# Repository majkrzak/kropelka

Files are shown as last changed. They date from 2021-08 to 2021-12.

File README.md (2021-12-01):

kropelka
========

Fluid level ISM band radio sensor.

Introduction
------------

Aim of the project was to utilise the cc1101 board I recently acquired. Because of the last events in my neighbourhood, I came up with idea of creating the sensor detecting water level above the threshold.

Electronic Parts
-----

### ATtiny13A
Atmel picoPower 8-Bit AVR microcontroller.

### E07 M1101-SMA
EBYTE CC1191 Wireless Module.

### DFR0579
DFRobot Solar Power Manager Micro.

### Solar Panel
DFRobot 2V 160mA Solar Panel.

### Lipo battery
Akyga Li-Pol cell 190mAh 1S 3,7V

### CMW55
Magnetic fluid level sensor.

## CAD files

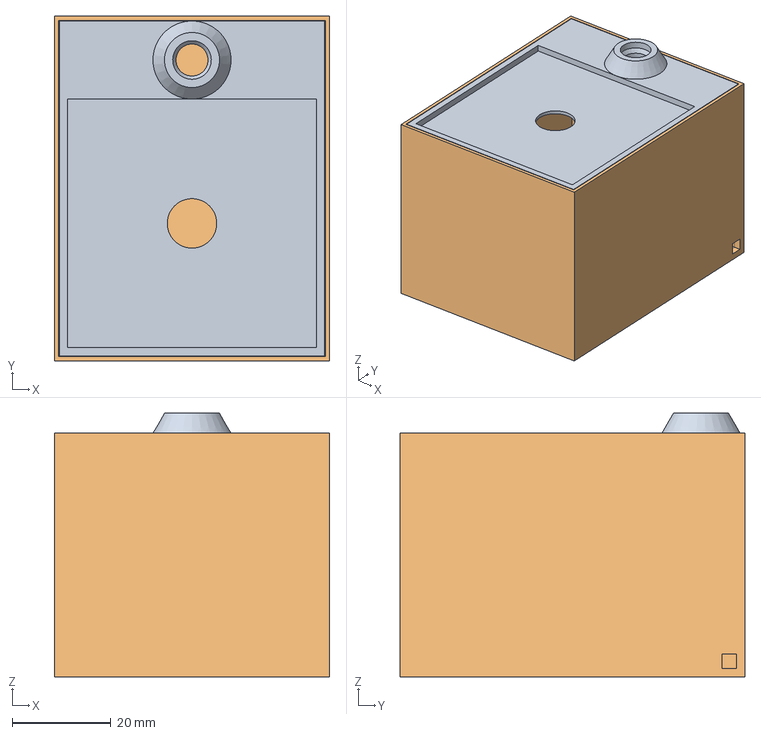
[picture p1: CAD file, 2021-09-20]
case/case.FCStd
55.7 x 69.8 x 53.3 mm
Lead

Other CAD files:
case/case.obj

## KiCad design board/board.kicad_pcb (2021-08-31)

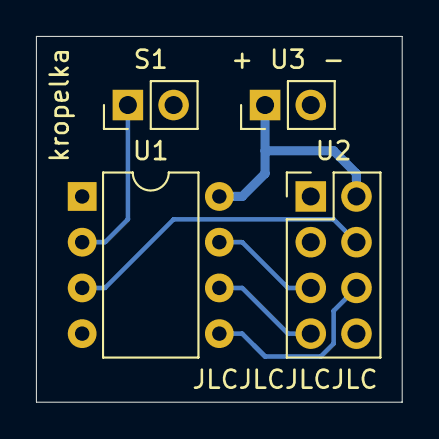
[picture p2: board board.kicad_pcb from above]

Board: 2 copper layers, 20.3 x 20.3 mm, 4 parts (0 on the bottom side), 7 nets.

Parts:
S1: Float_Switch; PinHeader_1x02_P2.54mm_Vertical
U1: ATtiny13A-PU; DIP-8_W7.62mm
U2: E07-M1101D
U3: DFR0579; PinHeader_1x02_P2.54mm_Vertical

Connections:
GND: S1.2, U1.4, U2.1, U3.2
unnamed: S1.1, U1.2
unnamed: U1.3, U2.4
unnamed: U1.5, U2.6
unnamed: U1.6, U2.7
unnamed: U1.7, U2.5
VCC: U1.8, U2.2, U3.1

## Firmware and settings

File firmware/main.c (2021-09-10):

#include "cc1101.h"
#include "mcu.h"
#include "radio.h"
#include "sensor.h"
#include "spi.h"
#include "watchdog.h"

struct __attribute__((packed, scalar_storage_order("big-endian"))) {
  uint8_t uuid[16];
  uint32_t counter;
  uint8_t state;
} packet = {.uuid = (uint8_t[]){PACKET_UUID}, .counter = 0};

int main() {
  mcu_init();
  watchdog_init();
  sensor_init();
  spi_init();
  cc1101_init();
  radio_init();

  do {
    radio_sleep();
    watchdog_arm();
    mcu_sleep();
    radio_wake();
    radio_calibrate();
    packet.counter++;
    packet.state = sensor_state();
    radio_send((uint8_t *)&packet);
  } while (1);
}

_Static_assert(sizeof packet == RADIO_PKTLEN);

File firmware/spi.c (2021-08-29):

#include "spi.h"

#include <avr/io.h>
#include <util/delay.h>

#define DELAY 10

void spi_init() {
  DDRB |= 1 << PB0;
  DDRB |= 1 << PB2;
  DDRB |= 1 << PB4;
  DDRB &= ~(1 << PB1);
}

void spi_select() { PORTB &= ~(1 << PB4); }

void spi_wait() {
  while (PORTB & (1 << PB1))
    ;
}

uint8_t spi_xfer(uint8_t in) {
  uint8_t out = 0;
  for (int8_t i = 7; i >= 0; --i) {
    // Write bit
    if ((in >> i) & 1) {
      PORTB |= (1 << PB0);
    } else {
      PORTB &= ~(1 << PB0);
    }
    _delay_us(DELAY);
    // Read bit
    out |= (PINB >> PB0) & 1;
    // tick the clock
    PORTB |= (1 << PB2);
    _delay_us(DELAY);
    PORTB &= ~(1 << PB2);
  }
  return out;
}

void spi_deselect() {
  PORTB |= (1 << PB4);
  _delay_us(DELAY);
}

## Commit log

2021-08-20 Add SPI library
2021-08-28 Add SPI timing
2021-08-28 Fix SPI
2021-08-28 Add first test transmission\n rtl_433 -X "name=kropelka,modulation=OOK_MC_ZEROBIT,short=844,l=0,r=1672,preamble=aaabba,get=test:@0:{32}"
    [main.c]
2021-08-29 Reduce spi timings
2021-08-29 Add sensor state check
2021-08-30 Add kicad library with E07-M1101D board
2021-08-30 Add Floating Switch to kicad Library
2021-08-30 Update E07 footprint
2021-08-31 Add Kicad project with first board version
    [board.kicad_pcb, board.sch]
2021-08-31 Add silkscreen +/- markings
    [board.kicad_pcb]
2021-08-31 Small schematic fixes
    [board.sch]
2021-08-31 Set JLCPCB export settings
    [board.kicad_pcb]
2021-09-10 Add case schema
    [case.FCStd]
2021-09-18 Rework case
    [case.FCStd]
2021-09-18 Add rants
    [case.FCStd]
2021-09-18 Add holes
    [case.FCStd]
2021-09-18 Add cover
    [case.FCStd]
2021-09-20 Rework cover, add MasterSketch
    [case.FCStd]
2021-09-20 Model the case
    [case.FCStd]
2021-09-20 Rename the case
    [case.FCStd]
2021-09-20 Add generated assets
    [case.obj]
